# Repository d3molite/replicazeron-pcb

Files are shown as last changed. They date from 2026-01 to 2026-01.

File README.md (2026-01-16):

This is an extension project to the replicazeron repository by [9R](https://github.com/9R/replicazeron/tree/main). 

I wanted a custom made PCB to allow for easier wiring. 
Once I have built mine, I will update this doc with a BOM of parts that you will need. 

I opted for SMT Diodes due to space reasons.

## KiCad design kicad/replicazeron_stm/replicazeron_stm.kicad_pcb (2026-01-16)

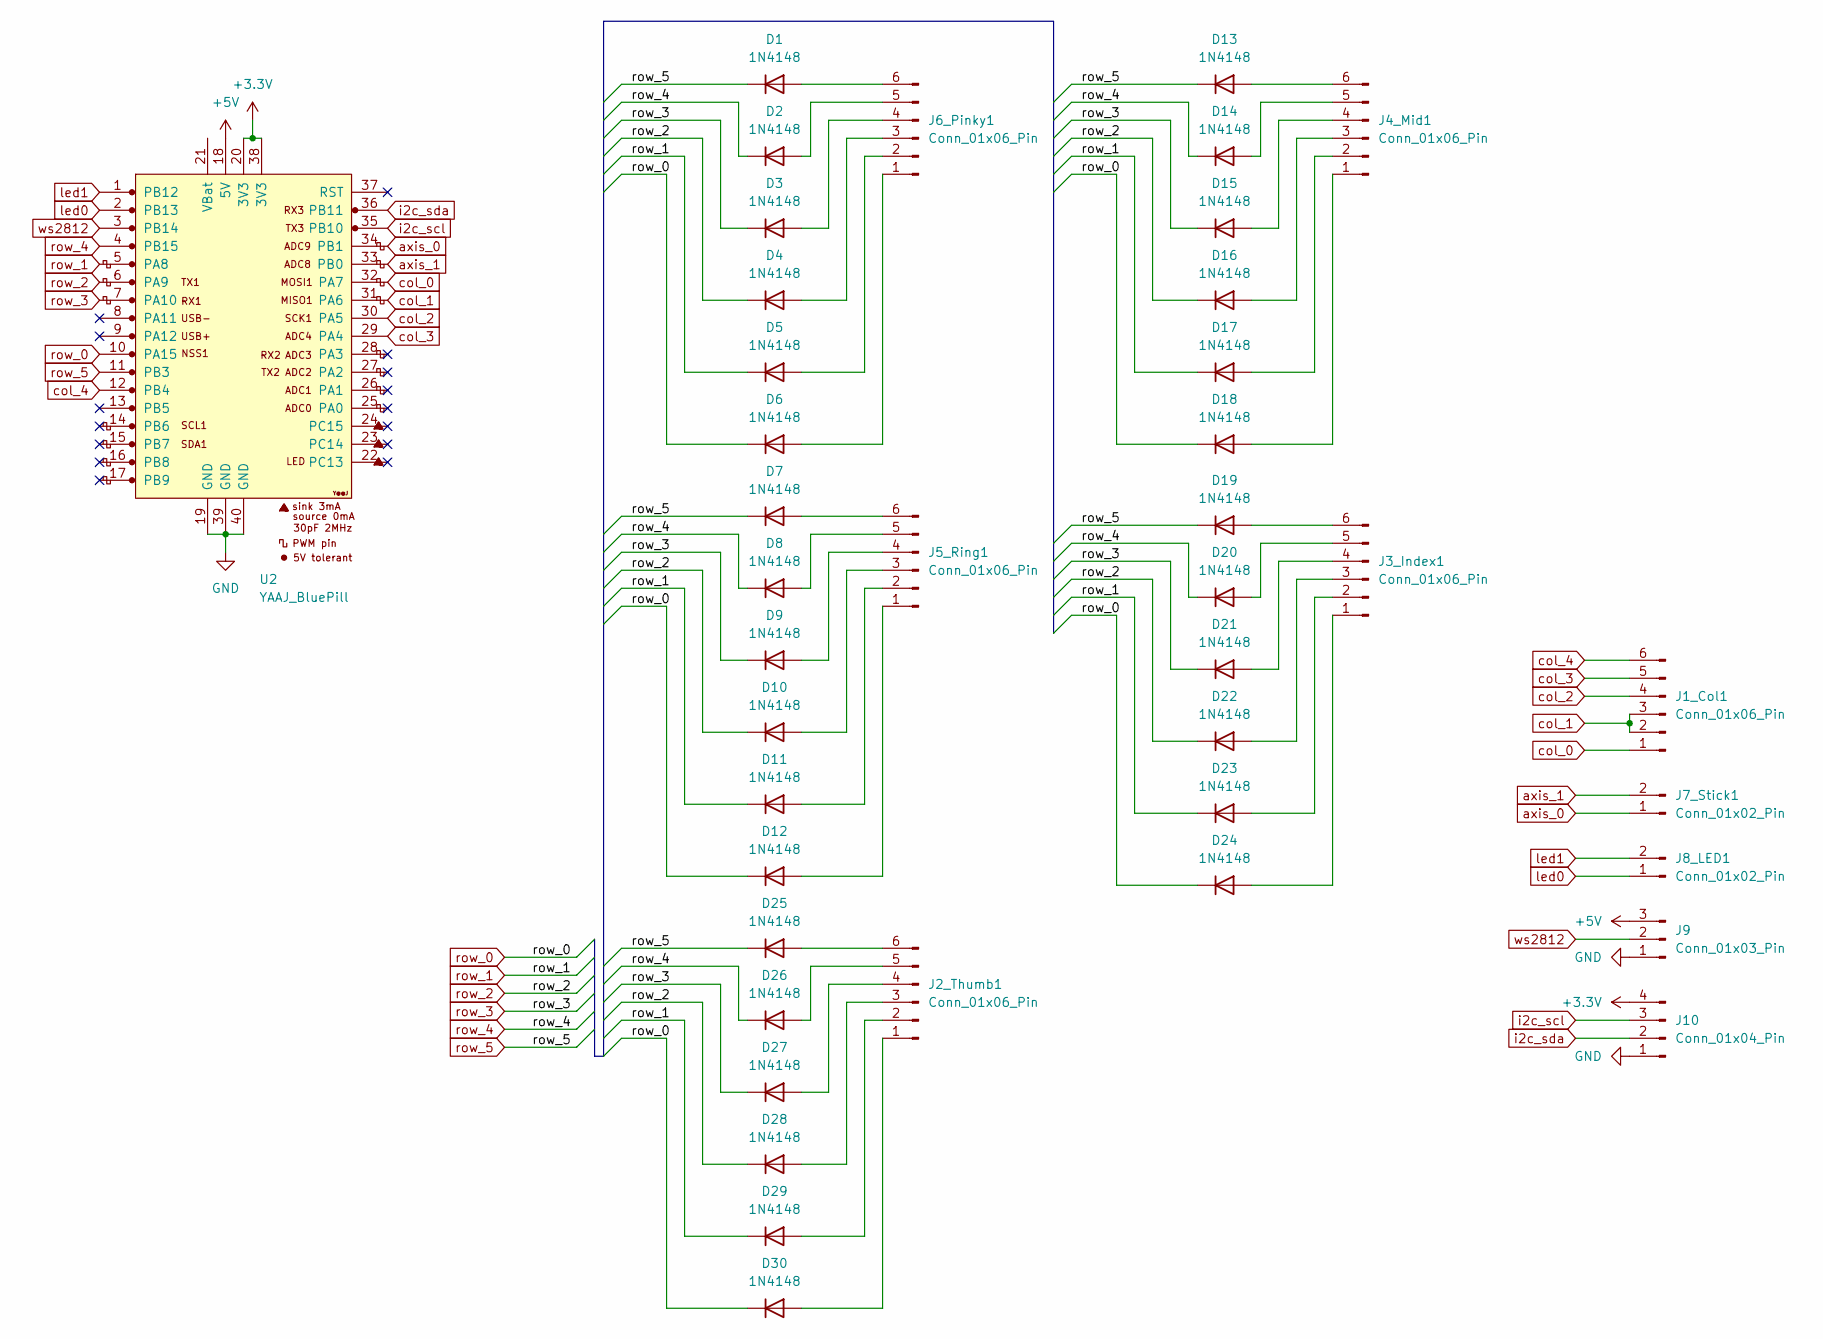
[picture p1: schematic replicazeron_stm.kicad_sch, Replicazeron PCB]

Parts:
D1, D2, D3, D4, D5, D6, D7, D8, D9, D10, D11, D12, D13, D14, D15, D16, D17, D18, D19, D20, D21, D22, D23, D24, D25, D26, D27, D28, D29, D30: 1N4148; D_SOD-323F
J1_Col1, J2_Thumb1, J3_Index1, J4_Mid1, J5_Ring1, J6_Pinky1: Conn_01x06_Pin; JST_XH_B6B-XH-A_1x06_P2.50mm_Vertical
J7_Stick1, J8_LED1: Conn_01x02_Pin; JST_XH_B2B-XH-A_1x02_P2.50mm_Vertical
J9: Conn_01x03_Pin; JST_XH_B3B-XH-A_1x03_P2.50mm_Vertical
J10: Conn_01x04_Pin; JST_XH_B4B-XH-A_1x04_P2.50mm_Vertical
U2: YAAJ_BluePill; YAAJ_BluePill_1

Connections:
+3.3V: J10.4, U2.20 (3V3), U2.38 (3V3)
+5V: J9.3, U2.18 (5V)
GND: J9.1, J10.1, U2.19 (GND), U2.39 (GND), U2.40 (GND)
unnamed: D1.2 (A), J6_Pinky1.6
unnamed: D2.2 (A), J6_Pinky1.5
unnamed: D3.2 (A), J6_Pinky1.4
unnamed: D4.2 (A), J6_Pinky1.3
unnamed: D5.2 (A), J6_Pinky1.2
unnamed: D6.2 (A), J6_Pinky1.1
unnamed: D7.2 (A), J5_Ring1.6
unnamed: D8.2 (A), J5_Ring1.5
unnamed: D9.2 (A), J5_Ring1.4
unnamed: D10.2 (A), J5_Ring1.3
unnamed: D11.2 (A), J5_Ring1.2
unnamed: D12.2 (A), J5_Ring1.1
unnamed: D13.2 (A), J4_Mid1.6
unnamed: D14.2 (A), J4_Mid1.5
unnamed: D15.2 (A), J4_Mid1.4
unnamed: D16.2 (A), J4_Mid1.3
unnamed: D17.2 (A), J4_Mid1.2
unnamed: D18.2 (A), J4_Mid1.1
unnamed: D19.2 (A), J3_Index1.6
unnamed: D20.2 (A), J3_Index1.5
unnamed: D21.2 (A), J3_Index1.4
unnamed: D22.2 (A), J3_Index1.3
unnamed: D23.2 (A), J3_Index1.2
unnamed: D24.2 (A), J3_Index1.1
unnamed: D25.2 (A), J2_Thumb1.6
unnamed: D26.2 (A), J2_Thumb1.5
unnamed: D27.2 (A), J2_Thumb1.4
unnamed: D28.2 (A), J2_Thumb1.3
unnamed: D29.2 (A), J2_Thumb1.2
unnamed: D30.2 (A), J2_Thumb1.1
axis_0: J7_Stick1.1, U2.34 (PB1)
axis_1: J7_Stick1.2, U2.33 (PB0)
col_0: J1_Col1.1, U2.32 (PA7)
col_1: J1_Col1.2, J1_Col1.3, U2.31 (PA6)
col_2: J1_Col1.4, U2.30 (PA5)
col_3: J1_Col1.5, U2.29 (PA4)
col_4: J1_Col1.6, U2.12 (PB4)
i2c_scl: J10.3, U2.35 (PB10)
i2c_sda: J10.2, U2.36 (PB11)
led0: J8_LED1.1, U2.2 (PB13)
led1: J8_LED1.2, U2.1 (PB12)
row_0: D6.1 (K), D12.1 (K), D18.1 (K), D24.1 (K), D30.1 (K), U2.10 (PA15)
row_1: D5.1 (K), D11.1 (K), D17.1 (K), D23.1 (K), D29.1 (K), U2.5 (PA8)
row_2: D4.1 (K), D10.1 (K), D16.1 (K), D22.1 (K), D28.1 (K), U2.6 (PA9)
row_3: D3.1 (K), D9.1 (K), D15.1 (K), D21.1 (K), D27.1 (K), U2.7 (PA10)
row_4: D2.1 (K), D8.1 (K), D14.1 (K), D20.1 (K), D26.1 (K), U2.4 (PB15)
row_5: D1.1 (K), D7.1 (K), D13.1 (K), D19.1 (K), D25.1 (K), U2.11 (PB3)
ws2812: J9.2, U2.3 (PB14)

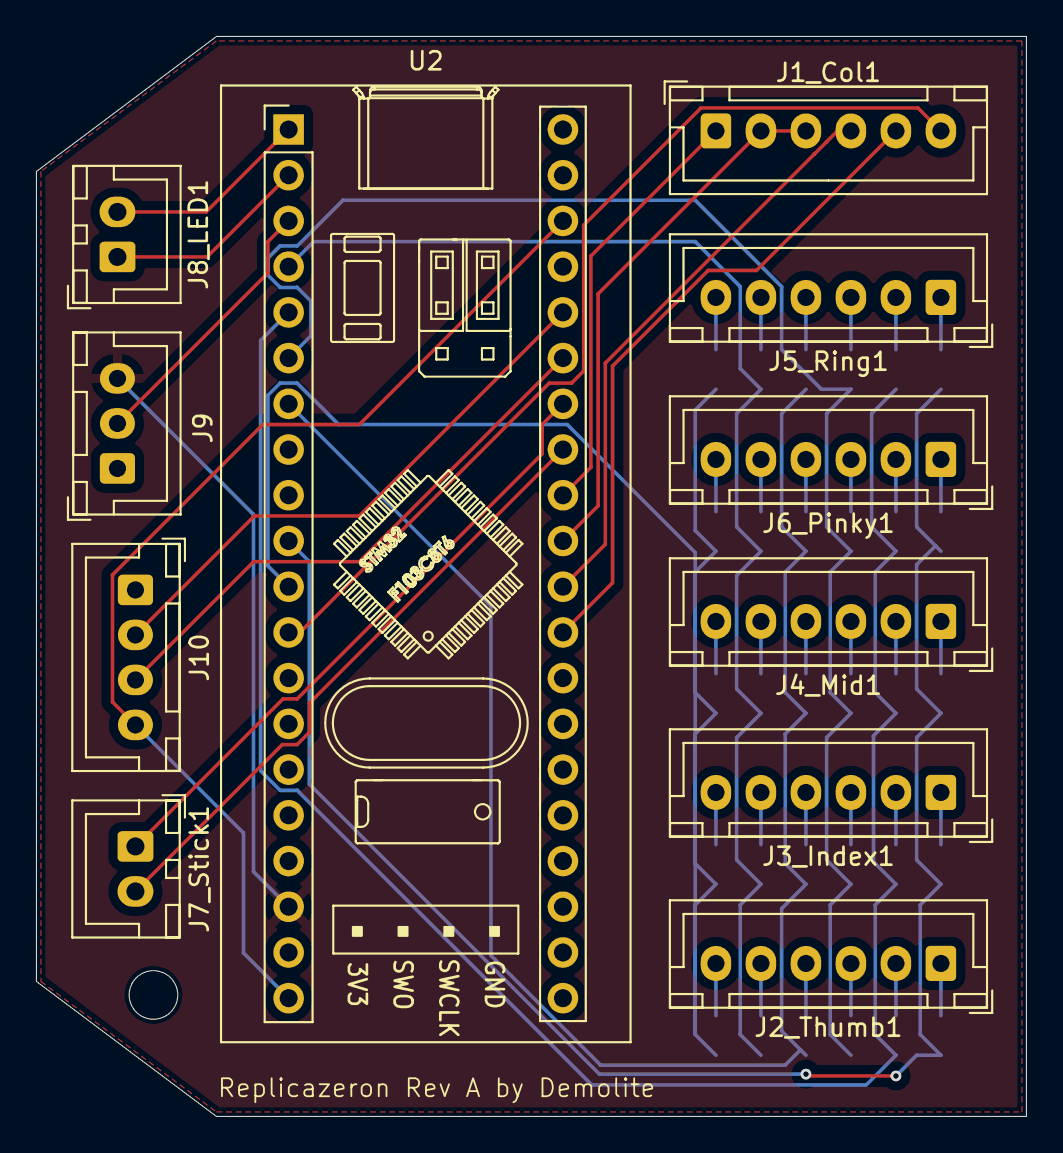
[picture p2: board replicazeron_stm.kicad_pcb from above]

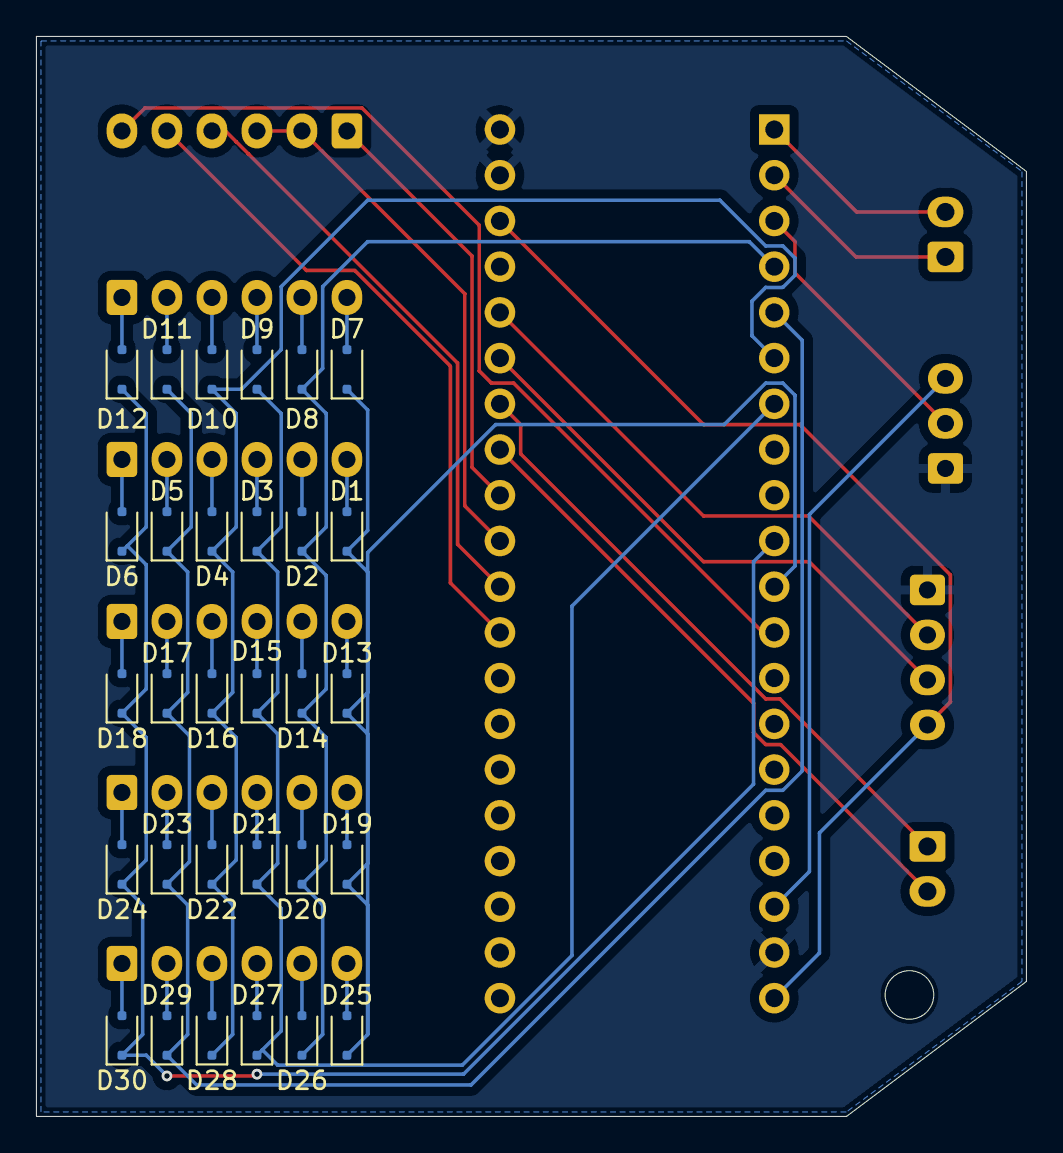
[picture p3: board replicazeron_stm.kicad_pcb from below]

Board: 2 copper layers, 55.0 x 60.0 mm, 41 parts (30 on the bottom side), 51 nets.

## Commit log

2026-01-16 Pre Routing PCB Version A
    [replicazeron_stm.kicad_pcb, replicazeron_stm.kicad_sch]
2026-01-16 Routing PCB Version A
    [replicazeron_stm.kicad_pcb, replicazeron_stm.kicad_sch]
2026-01-16 Fabrication Files Version A
    [replicazeron_stm-B_Cu.gbr, replicazeron_stm-B_Mask.gbr, replicazeron_stm-B_Paste.gbr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]
